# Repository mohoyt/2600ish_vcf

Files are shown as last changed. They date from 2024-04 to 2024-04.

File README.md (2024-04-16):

# 2600ish_vcf

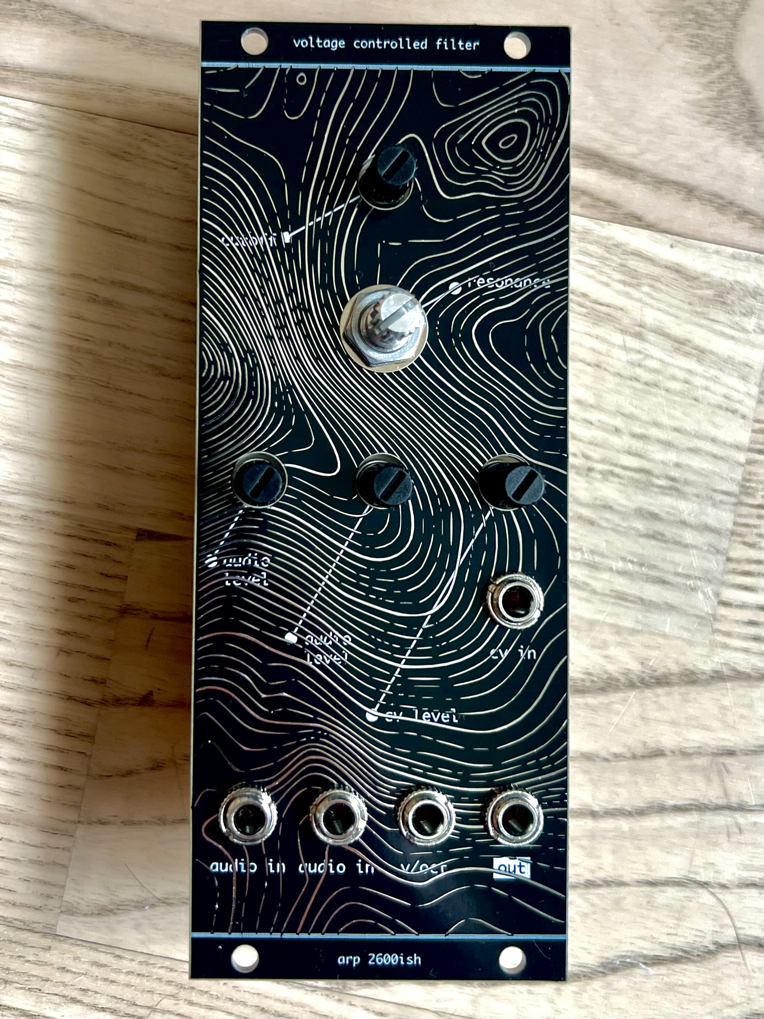
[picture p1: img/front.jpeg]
Panel front


This is a fully through hole component Eurorack voltage controlled low pass filter based on the one in the ARP 2600. There were different filters in the ARP 2600 at different times, this is the 4072 variety and is not a diode ladder filter like the early one. 

Inspiration and the starting point for schematics for this filter taken from [Eddy Bergman](https://www.eddybergman.com/2020/03/synthesizer-build-part-21-arp2600.html) and [Yusynth](http://yusynth.net/Modular/EN/ARPVCF/index.html)

This module is 10hp (~50mm) wide and runs on a standard dual rail 12v eurorack supply.

See a longer write up of this project on my website: [https://mohoyt.com/blog/2024/2600ish-vcf](https://mohoyt.com/blog/2024/2600ish-vcf)

Special thanks to [PCBWay](https://pcbway.com) for sponsoring this build.

## Samples

See [samples](samples) folder or examples on Soundcloud:
- [Triangle wave](https://soundcloud.com/moses-hoyt/2600ish-vcf-triangle-wave)
- [Square wave](https://soundcloud.com/moses-hoyt/2600ish-vcf-square-wave)
- [Sawtooth wave](https://soundcloud.com/moses-hoyt/2600ish-vcf-sawtooth-wave)

## Gerbers

See the most recent gerbers on the releases tab. The gerbers included are configured for PCBWay. There are two sets, one for the panel and one for the PCB. 

## Bill of Materials

See the iBOM in the [BOM](bom) folder. You will need matched 2N3906 transistors and ideally polystyrene caps for the four filter poles.

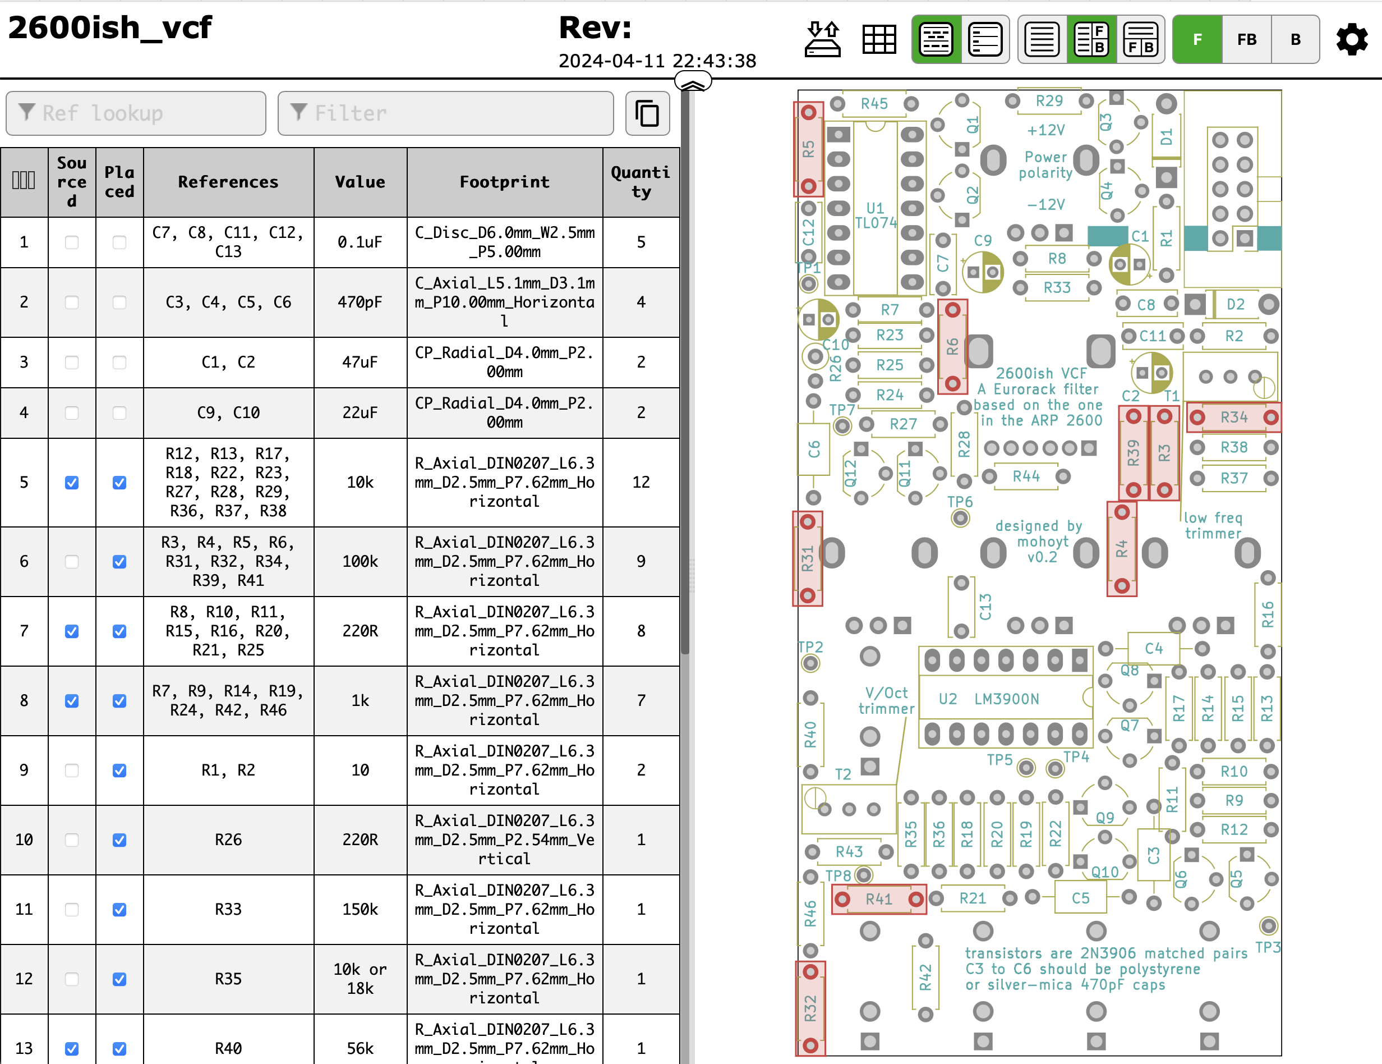
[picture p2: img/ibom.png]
iBOM


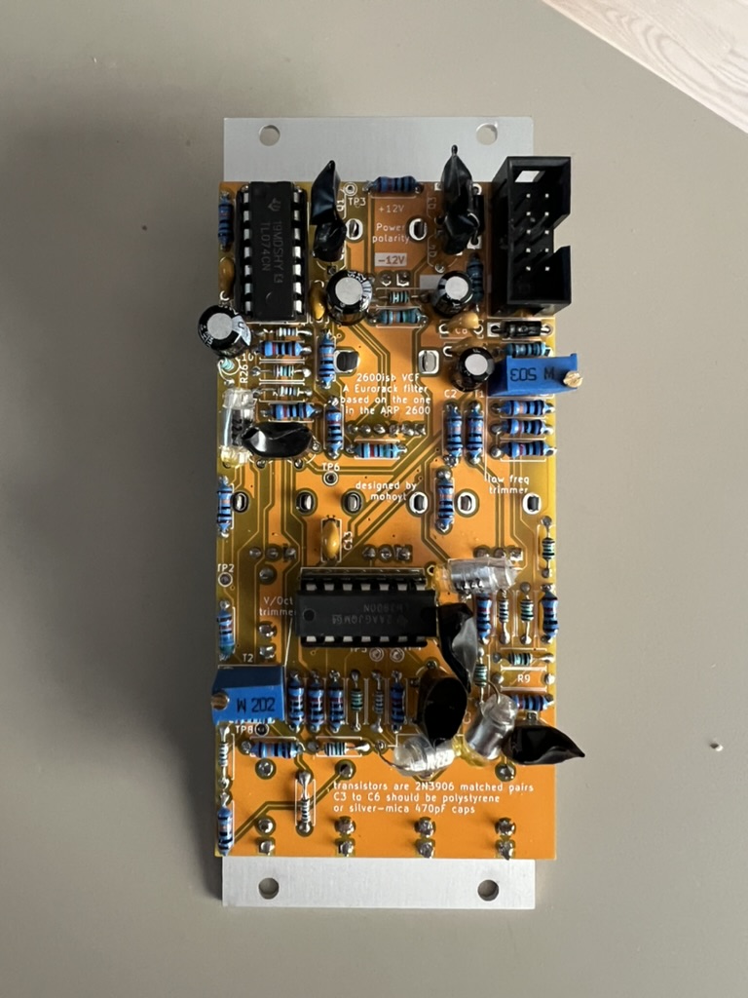
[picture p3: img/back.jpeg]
Panel back


## Calibration and tuning 

Taken from [Yusynth](http://yusynth.net/Modular/index_en.html)

### V/Octave tracking:
- Turn the frequency knob to 0, turn all the control knobs to 0 (fully counter clockwise)
- Apply 0V to the V/Oct input
- Measure the voltage at the basis of Q3 (node between R46, R30 to R34), adjust T1 (low freq trimmer) in order to obtain 0V at this very node.
- Apply 1V to the V/Oct input
- Adjust T2 (v/octave trimmer) in order to measure 18.7mV at the previous node.
- Apply 0V to the V/Oct input
- Adjust T1 (low freq trimmer) in order to measure -187mV at this very node.
- After the Frequency range stting (see below) you may set the filter to oscilltion mode and slightly adjust T2 in order to achieve a good V/Octave tracking.

### Frequency range setting :
- Apply a 40Hz squarewave to one of the audio input, connect the output to an amplifier.
- Set the FREQUENCY potentiometer to 0 (fully counter clockwise)
- Adjust T1 (low freq trimmer) until no signal can be heard at the output, that's it!

## Notes and known issues
- v0.1 had an issue with an extra connection around R9, but fixable on the board by rerouting R9, cutting traces and adding a bodge wire. This is fixed in v0.2
- For the panel ensure that the silkscreen is *not* subtracted from the soldermask otherwise parts of the lines and words will be difficult to read

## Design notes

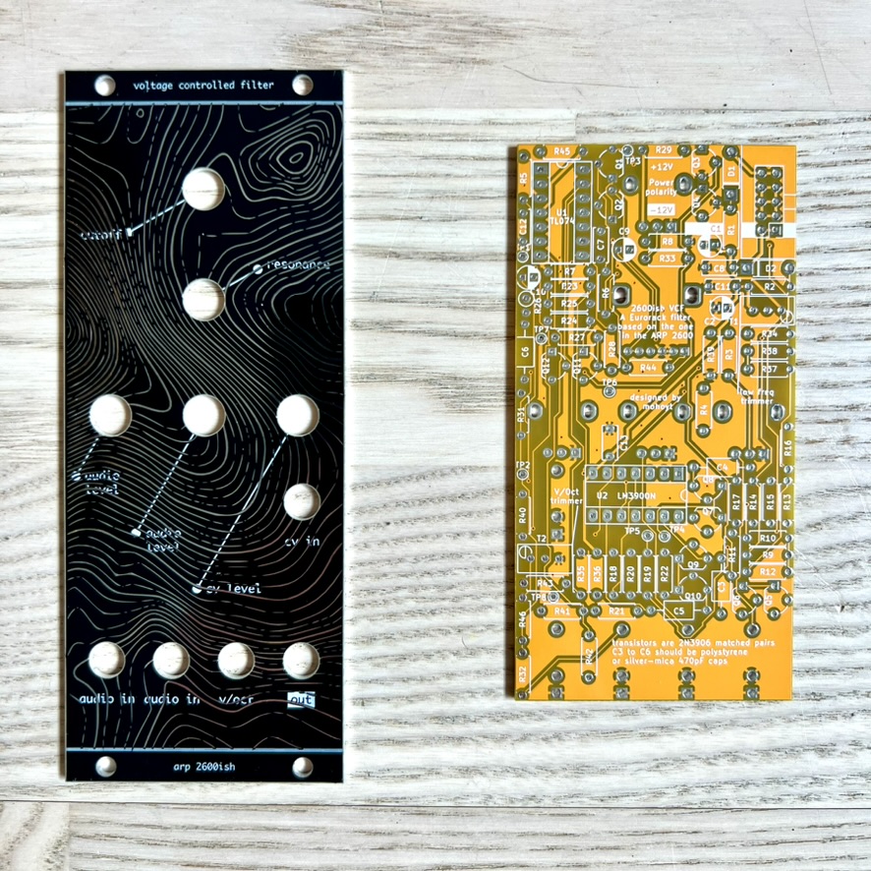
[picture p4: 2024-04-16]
img/pcb and panel.jpeg

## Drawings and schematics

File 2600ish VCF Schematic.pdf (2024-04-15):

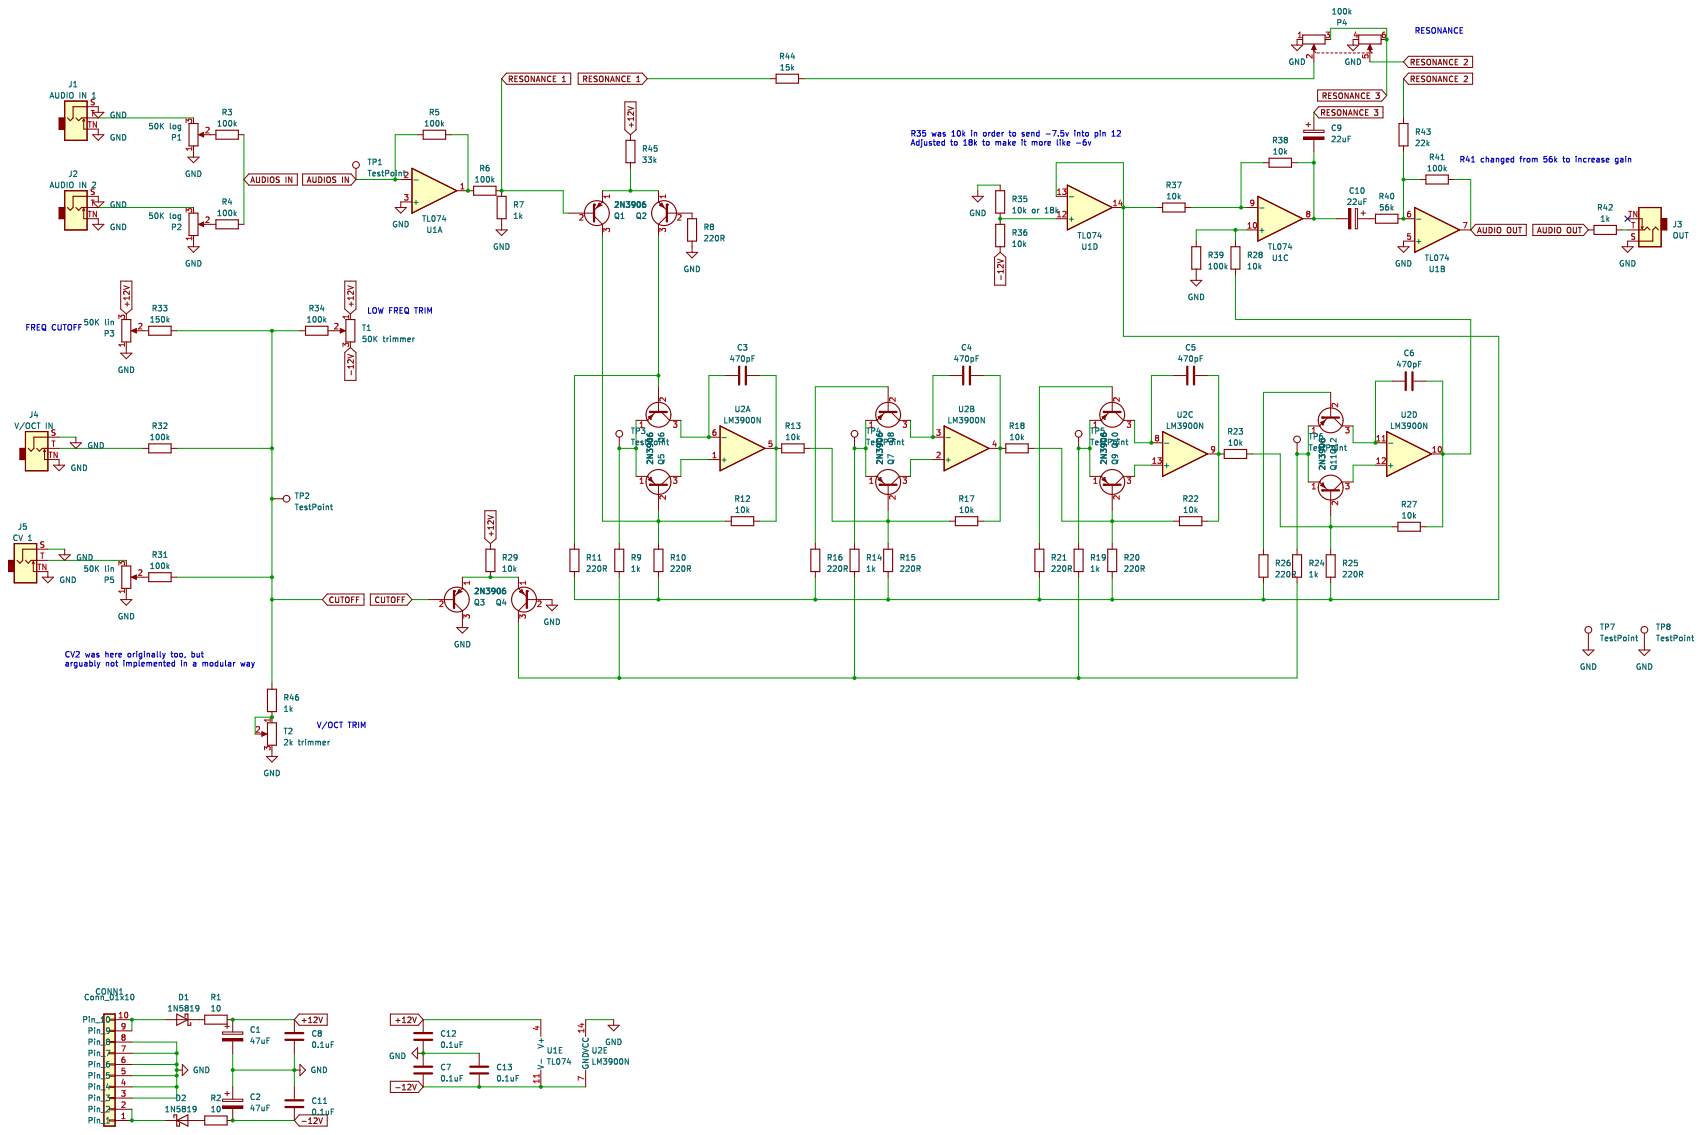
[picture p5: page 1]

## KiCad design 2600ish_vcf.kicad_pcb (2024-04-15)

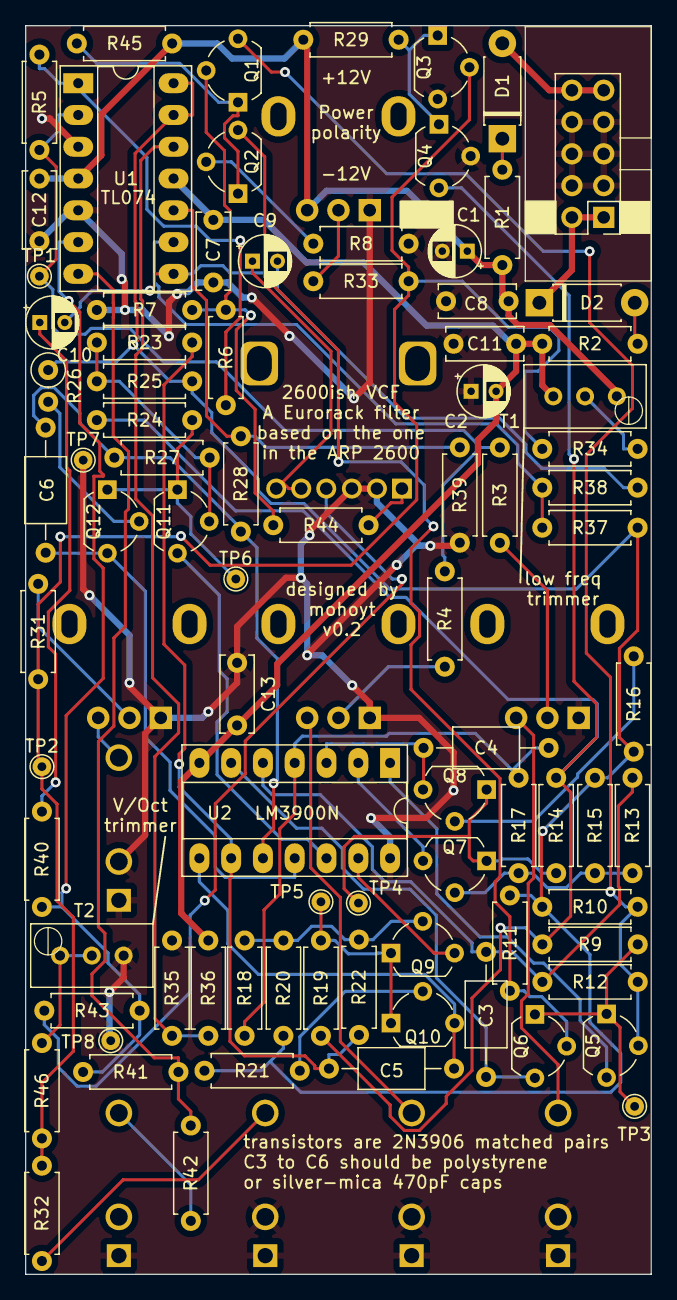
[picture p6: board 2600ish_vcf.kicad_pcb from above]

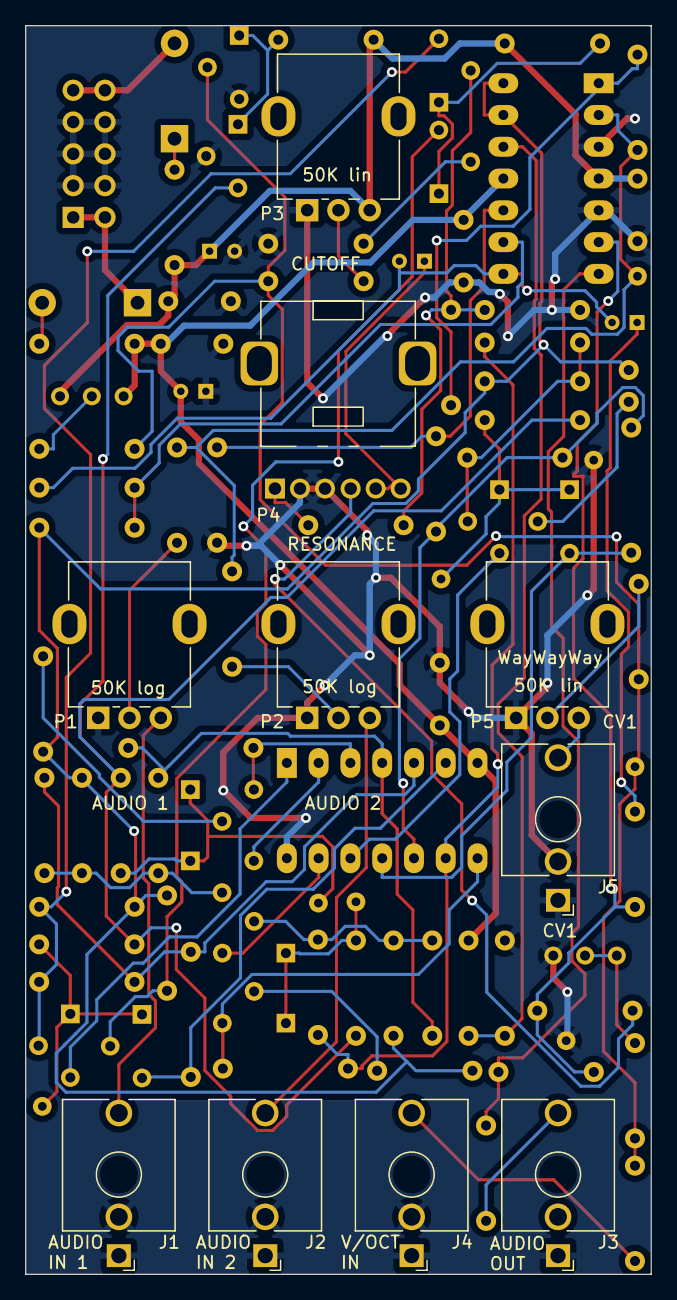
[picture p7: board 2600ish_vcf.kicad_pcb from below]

Board: 2 copper layers, 50.0 x 99.8 mm, 95 parts (10 on the bottom side), 61 nets.

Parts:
C1, C2: 47uF; CP_Radial_D4.0mm_P2.00mm
C3, C4, C5, C6: 470pF; C_Axial_L5.1mm_D3.1mm_P10.00mm_Horizontal
C7, C8, C11, C12, C13: 0.1uF; C_Disc_D6.0mm_W2.5mm_P5.00mm
C9, C10: 22uF; CP_Radial_D4.0mm_P2.00mm
CONN1: Conn_01x10; PinHeader_2x05_P2.54mm_Vertical_Shroud
D1, D2: 1N5819; D_DO-41_SOD81_P7.62mm_Horizontal
J1: AUDIO IN 1; Jack_3.5mm_QingPu_WQP-PJ398SM_Vertical_CircularHoles
J2: AUDIO IN 2; Jack_3.5mm_QingPu_WQP-PJ398SM_Vertical_CircularHoles
J3: OUT; Jack_3.5mm_QingPu_WQP-PJ398SM_Vertical_CircularHoles
J4: V/OCT IN; Jack_3.5mm_QingPu_WQP-PJ398SM_Vertical_CircularHoles
J5: CV 1; Jack_3.5mm_QingPu_WQP-PJ398SM_Vertical_CircularHoles
P1, P2: 50K log; Potentiometer_Alpha_RD901F-40-00D_Single_Vertical
P3, P5: 50K lin; Potentiometer_Alpha_RD901F-40-00D_Single_Vertical
P4: 100k; Potentiometer_Double_Vertical_Befaco
Q1, Q2, Q3, Q4, Q5, Q6, Q7, Q8, Q9, Q10, Q11, Q12: 2N3906; TO-92_Wide
R1, R2: 10; R_Axial_DIN0207_L6.3mm_D2.5mm_P7.62mm_Horizontal
R3, R4, R5, R6, R31, R32, R34, R39, R41: 100k; R_Axial_DIN0207_L6.3mm_D2.5mm_P7.62mm_Horizontal
R7, R9, R14, R19, R24, R42, R46: 1k; R_Axial_DIN0207_L6.3mm_D2.5mm_P7.62mm_Horizontal
R8, R10, R11, R15, R16, R20, R21, R25: 220R; R_Axial_DIN0207_L6.3mm_D2.5mm_P7.62mm_Horizontal
R12, R13, R17, R18, R22, R23, R27, R28, R29, R36, R37, R38: 10k; R_Axial_DIN0207_L6.3mm_D2.5mm_P7.62mm_Horizontal
R26: 220R; R_Axial_DIN0207_L6.3mm_D2.5mm_P2.54mm_Vertical
R33: 150k; R_Axial_DIN0207_L6.3mm_D2.5mm_P7.62mm_Horizontal
R35: 10k or 18k; R_Axial_DIN0207_L6.3mm_D2.5mm_P7.62mm_Horizontal
R40: 56k; R_Axial_DIN0207_L6.3mm_D2.5mm_P7.62mm_Horizontal
R43: 22k; R_Axial_DIN0207_L6.3mm_D2.5mm_P7.62mm_Horizontal
R44: 15k; R_Axial_DIN0207_L6.3mm_D2.5mm_P7.62mm_Horizontal
R45: 33k; R_Axial_DIN0207_L6.3mm_D2.5mm_P7.62mm_Horizontal
T1: 50K trimmer; Potentiometer_Bourns_3296W_Vertical
T2: 2k trimmer; Potentiometer_Bourns_3296W_Vertical
TP1, TP2, TP3, TP4, TP5, TP6, TP7, TP8: TestPoint; TestPoint_THTPad_D1.5mm_Drill0.7mm
U1: TL074; DIP-14_W7.62mm_Socket_LongPads
U2: LM3900N; DIP-14_W7.62mm_Socket_LongPads

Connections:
+12V: C1.1, C8.1, C12.1, P3.3, R1.2, R29.2, R45.2, T1.1, U1.4 (V+)
-12V: C2.2, C7.2, C11.2, C13.2, R2.2, R36.2, T1.3, U1.11 (V-), U2.7 (GND)
AUDIO OUT: R41.2, R42.2, U1.7
AUDIOS IN: R3.2, R4.2, R5.1, TP1.1, U1.2 (-)
CUTOFF: Q3.2 (B), R31.2, R32.2, R33.2, R34.1, R46.2, TP2.1
GND: C1.2, C2.1, C7.1, C8.2, C11.1, C12.2, C13.1, CONN1.3, CONN1.4, CONN1.5, CONN1.6, CONN1.7, CONN1.8, J1.S, J1.TN, J2.S, J2.TN, J3.S, J4.S, J4.TN, J5.S, J5.TN, P1.1, P2.1, P3.1, P4.1, P4.4, P5.1, Q3.3 (C), Q4.2 (B), R7.1, R8.1, R35.1, R39.1, T2.3, TP7.1, TP8.1, U1.3 (+), U1.5 (+), U2.14 (VCC)
unnamed: C3.2, R12.1, R13.2, U2.5
unnamed: C4.2, R17.1, R18.2, U2.4
unnamed: C5.2, R22.1, R23.2, U2.9
unnamed: C6.2, R27.1, R28.1, U2.10
unnamed: C10.1, R40.1
unnamed: C9.2, C10.2, R38.2, U1.8
unnamed: CONN1.1, CONN1.2, D2.1 (K)
unnamed: CONN1.9, CONN1.10, D1.2 (A)
unnamed: D1.1 (K), R1.1
unnamed: D2.2 (A), R2.1
unnamed: J1.T, P1.3
unnamed: J2.T, P2.3
unnamed: J3.T, R42.1
unnamed: J4.T, R32.1
unnamed: J5.T, P5.3
unnamed: P1.2, R3.1
unnamed: P2.2, R4.1
unnamed: P3.2, R33.1
unnamed: P4.2, R44.1
unnamed: P5.2, R31.1
unnamed: Q1.3 (C), Q5.2 (B), R10.2, R12.2
unnamed: Q1.1 (E), Q2.1 (E), R45.1
unnamed: Q2.2 (B), R8.2
unnamed: Q2.3 (C), Q6.2 (B), R11.2
unnamed: Q3.1 (E), Q4.1 (E), R29.1
unnamed: Q4.3 (C), R9.1, R14.1, R19.1, R24.1
unnamed: Q5.3 (C), U2.1 (+)
unnamed: Q5.1 (E), Q6.1 (E), R9.2, TP3.1
unnamed: C3.1, Q6.3 (C), U2.6 (-)
unnamed: Q7.2 (B), R13.1, R15.2, R17.2
unnamed: Q7.3 (C), U2.2 (+)
unnamed: Q7.1 (E), Q8.1 (E), R14.2, TP4.1
unnamed: Q8.2 (B), R16.2
unnamed: C4.1, Q8.3 (C), U2.3 (-)
unnamed: Q9.2 (B), R18.1, R20.2, R22.2
unnamed: Q9.3 (C), U2.13 (+)
unnamed: Q10.2 (B), R21.2
unnamed: C5.1, Q10.3 (C), U2.8 (-)
unnamed: Q9.1 (E), Q10.1 (E), R19.2, TP5.1
unnamed: Q11.2 (B), R23.1, R25.2, R27.2
unnamed: Q11.3 (C), U2.12 (+)
unnamed: Q11.1 (E), Q12.1 (E), R24.2, TP6.1
unnamed: Q12.2 (B), R26.2
unnamed: C6.1, Q12.3 (C), U2.11 (-)
unnamed: R5.2, R6.1, U1.1
unnamed: R34.2, T1.2
unnamed: R46.1, T2.1, T2.2
unnamed: R40.2, R41.1, R43.1, U1.6 (-)
unnamed: R28.2, R39.2, U1.10 (+)
unnamed: R37.2, R38.1, U1.9 (-)
unnamed: R35.2, R36.1, U1.12 (+)
unnamed: R10.1, R11.1, R15.1, R16.1, R20.1, R21.1, R25.1, R26.1, R37.1, U1.13 (-), U1.14
RESONANCE 1: Q1.2 (B), R6.2, R7.2, R44.2
RESONANCE 2: P4.5, R43.2
RESONANCE 3: C9.1, P4.3, P4.6

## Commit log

2024-02-07 Schematic done mostly
    [2600ish_vcf.kicad_pcb, 2600ish_vcf.kicad_sch]
2024-03-19 PCB layout started
    [2600ish_vcf.kicad_pcb, 2600ish_vcf.kicad_sch]
2024-03-21 component placement done
    [2600ish_vcf.kicad_pcb, 2600ish_vcf.kicad_sch]
2024-03-21 Some adjustments made for gain and footprint size
    [2600ish_vcf.kicad_pcb, 2600ish_vcf.kicad_sch]
2024-03-26 Clearer schematic
    [2600ish_vcf.kicad_pcb, 2600ish_vcf.kicad_sch]
2024-03-26 Schematic for split board done, updating PCB now
    [2600ish_vcf.kicad_pcb, 2600ish_vcf.kicad_sch]
2024-03-26 Main PCB pretty much done, panel work started
    [2600ish Panel.kicad_pcb, 2600ish Panel.kicad_sch, 2600ish_vcf.kicad_pcb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]
2024-03-31 New panel design with topography
    [2600ish Panel-B_Cu.gbr, 2600ish Panel-B_Mask.gbr, 2600ish Panel-B_Paste.gbr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]
2024-04-02 BOM added
2024-04-11 Schematic issue and related routing fixed and v0.2 created. New gerbers generated
    [2600ish Panel-B_Cu.gbr, 2600ish Panel-B_Mask.gbr, 2600ish Panel-B_Paste.gbr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]
2024-04-15 Readme updated and photos added
    [2600ish_vcf-B_Cu.gbr, 2600ish_vcf-B_Mask.gbr, 2600ish_vcf-B_Paste.gbr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]
2024-04-16 Samples added
